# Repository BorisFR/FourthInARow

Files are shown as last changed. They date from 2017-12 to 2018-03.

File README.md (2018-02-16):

# Fourth-In-A-Row

Le jeu des [R2-Builders](https://r2builders.fr) : Le jeu Puissance 4 avec la Force du Jedi !

- Idée originale : [@SuTaiBot](https://twitter.com/RUGeek2)

## ___I. Objectif___

L'objectif est de créer un jeu avec la thématique de Star Wars, par le travail des membres des R2-Builders.  
Le jeu choisi : un dérivé de Puissance 4. Le wikipedia du jeu en français : [Puissance 4](https://fr.wikipedia.org/wiki/Puissance_4). Et le wikipedia en anglais : [Connect 4 ou Four-in-a-row](https://en.wikipedia.org/wiki/Connect_Four). Le jeu sera décliné en deux versions.



### 1. Version dite "classique"

La version classique sera réalisée avec des jetons que l'on dépose dans les colonnes pour jouer, dans le pure style connu de tous, mais au look de Star Wars !

### 2. Version électronique

La version électronique viendra en complément de la version "classique" en supprimant ces jetons et en représentant les jetons par des LEDs et l'on choisira la colonne par des boutons.

### 3. Règles du jeu

Pendant un match, chaque joueur, à tour de rôle, dépose un jeton dans une des sept colonnes. Le jeton tombe au plus bas de la colonne. Une colonne peut contenir 6 jetons au maximum. Un match est gagné quand un des joueurs a aligné 4 jetons à l'horizontale, à la verticale ou en diagonale. S'il n'y a plus de place pour jouer un jeton et qu'il n'y a pas de gagnant, la partie est déclarée match nul.

## ___II. Version classique___

### 1. Le plateau de jeu

Voici un rendu de ce que ça pourrait donner :  
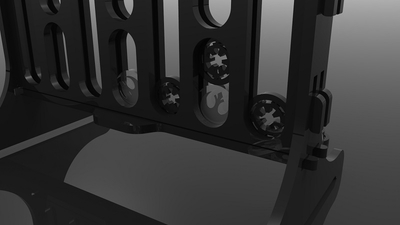
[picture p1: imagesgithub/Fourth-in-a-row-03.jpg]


#### a. Le plateau

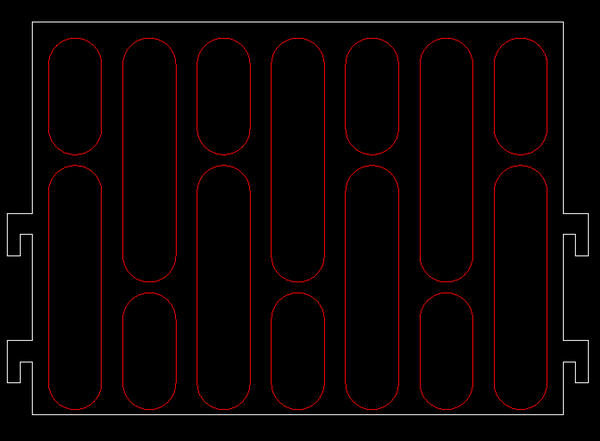
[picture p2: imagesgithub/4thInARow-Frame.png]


#### b. Les supports

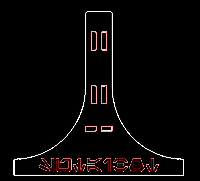
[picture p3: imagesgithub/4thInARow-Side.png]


### 2. Les jetons

plateau

## ___III. Version électronique___

### **1. Fonctionnement**

Le jeu a plusieurs états. Les inter-actions avec les joueurs seront variables en fonction de cet état. Voici le détail pour chaque état.

#### a. Attente

Dans cet phase, il n'y a pas de jeu en cours. Le programme est juste en attente d'une action des joueurs. Il passe alors à l'état suivant ***b***.

#### b. Choix du nombre de joueurs

Ici, il faut déterminer combien de joueurs participe au jeu. Ce nombre peut être de 1 ou 2. Si 2 joueurs est choisit, il s'agit d'un match opposant deux joueurs. Si il n'y a qu'un seul joueur, il jouera alors contre une  "Intelligence Artificielle" (IA). Afin de tester cette IA, il est possible de choisir zéro joueur : le programme joue alors contre lui-même.

#### c. Choix du joueur qui commence

Il faut maintenant décider qui commence parmi les deux opposants. Une fois ce choix effectué, le programme passe alors à l'état ***d***.

#### d. Placer un jeton

Le joueur en cours doit sélectionner une colonne pour déposer son jeton. Le programme passe alors à l'état ***e***.

#### e. Analyser le jeton

Si la colonne est pleine, retour à l'état ***d***.
Si quelqu'un a gagné, à l'état correspondant ***f*** ou ***g***.
S'il n'est plus possible de jouer, aller à l'état ***h***.
C'est au joueur suivant de jouer, aller à l'état ***d***.

#### f. Le joueur 1 a gagné

On affiche l'information et on passe à l'état ***i***.

#### g. Le joueur 2 a gagné

On affiche l'information et on passe à l'état ***i***.

#### h. C'est un match nul

On affiche l'information et on passe à l'état ***i***.

#### i. Animation de fin de jeu

On retourne à l'état ***a***.

### **2. Matériel**
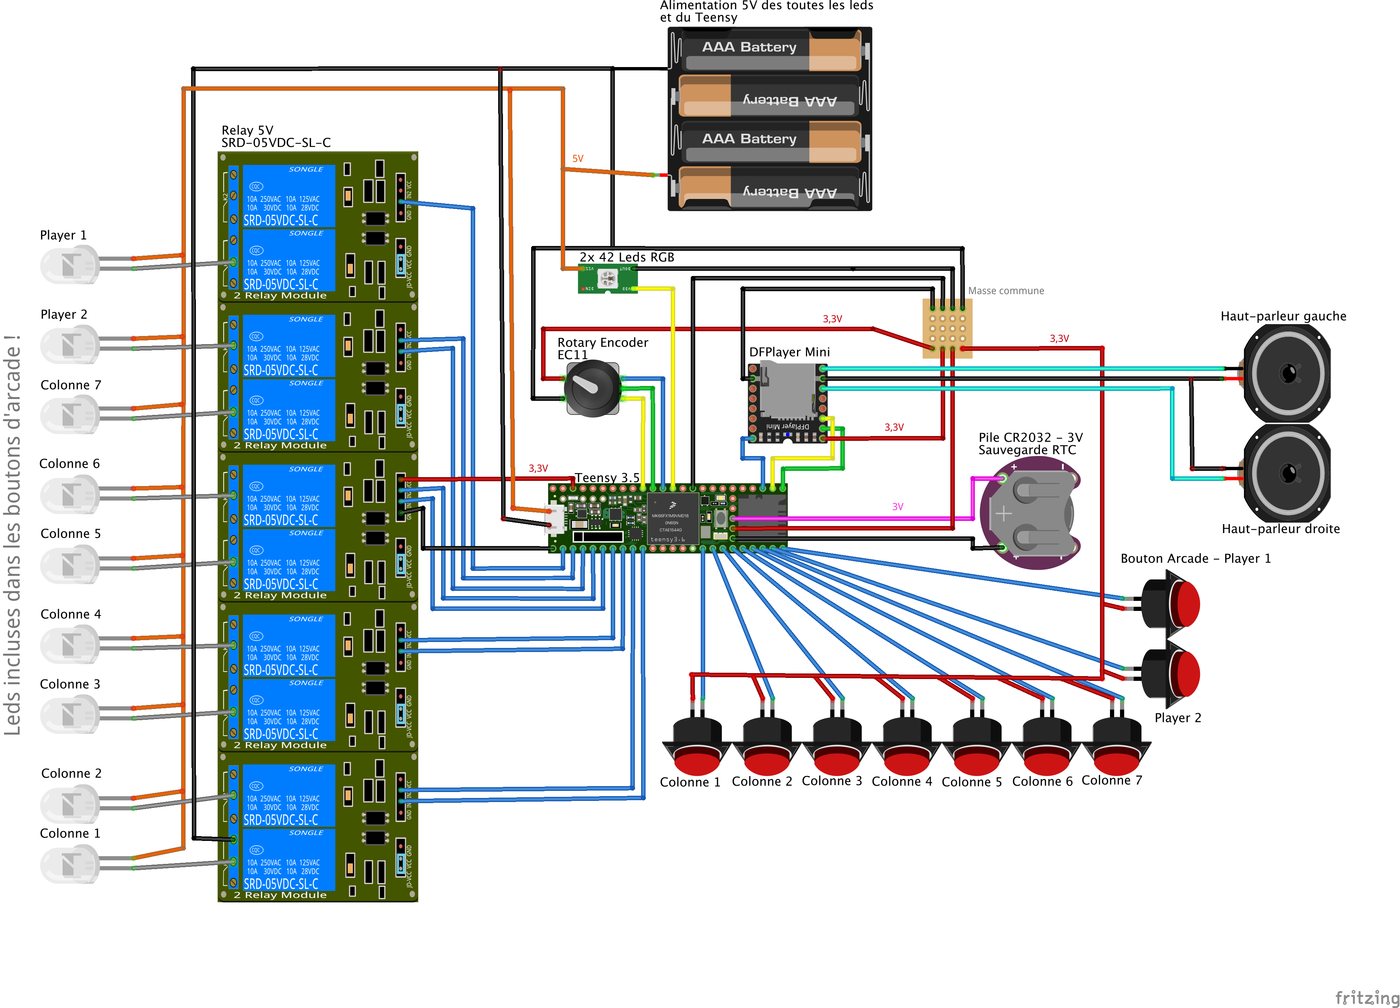
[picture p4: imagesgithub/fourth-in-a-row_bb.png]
Schéma

#### 1. Composant principal

Le cerveau de cette version électronique. On pourra utiliser divers matériels, voici ce que les membres ont utilisés / testés. Le programme fonctionne sur :

- Arduino Mega
- Adafruit Huzzah 32 (ESP32)
- Teensy 3.5

Il fonctionne certainement sur d'autres composants, mais ça n'a pas été testé.

#### 2. Composants additionnels

L'idée est d'avoir un panel d'options pour que vous puissiez réaliser votre propre jeu. Voici l'ensemble des composants qui sont activables dans le programme.

C'est dans le fichier ***"MyConfig.hpp"*** que vous indiquez votre configuration.

##### a. INPUT : Boutons pour jouer

Besoin :

- choisir le nombres de joueurs
- choisir qui commence
- choisir la colonne pour déposer le jeton

##### b. INPUT : Boutons pour audio

Gérer le son : augmenter le volume, baisser le volume, mute.

##### c. OUTPUT - Audio

Avoir la possibilité de jouer du son à divers moments pendant le jeu.

##### d. OUTPUT - LED

L'idée est d'avoir une LED par case, schématisant une case vide ou un jeton de joueur. Le tout représente un jeu complet.

Possibilités :

- 42 LEDs RGB

##### e. OUTPUT - Écran

Avoir un écran graphique sur lequel afficher des animations amusantes pendant le jeu. Pour le moment, cette option ne sera pas développée.

### 3. **Le programme**

Vous pouvez configurer votre installation dans le fichier "MyConfig.hpp". Vous pouvez alors compiler et télécharger votre programme sur votre arduino.

Le programme est développé en C++ "arduino".

#### "FourthInARow.ino"

Le point d'entrée est le fichier "FourthInARow.ino". Il s'agit du chef d'orchestre du jeu, celui qui va gérer les différents états du jeu et orchestrer l'ensemble des composants en fonction de cet état.

#### "Game.hpp"

Les fichiers Game.h et Game.cpp contiennent toute la logique d'exécution du jeu Puissance 4 en lui-même.

#### "GameInput.hpp"

Les fichiers "GameInput.hpp" et "GameInput.cpp" contiennent toute la logique pour que les joueurs puissent agir sur le jeu. A ce titre, c'est ici que l'on définit toutes les entrées possibles comme la gestion des boutons.
C'est fichiers contiennent une implémentation à vide de ces fonctions ! L'implémentation réelle est effectuée dans d'autres fichiers. Il suffit d'indiquer dans le fichier "MyConfig.hpp" l'implémentation réelle que vous voulez utiliser.

Voici les implémentations disponibles :

- GI_serial.hpp/cpp : interface Serial (utilisable uniquement en mode debug).
- GI_9buttons.hpp/.cpp : 7 boutons pour le choix de la colonne et 2 boutons pour le choix du nombre de joueurs.

#### "GameInputAudio.hpp"

Les fichiers "GameInputAudio.h" et "GameInputAudio.cpp" contiennent toute la logique pour agir sur l'audio : gérer le volume, couper le son, ...

Voici les implémentations disponibles concernant le son :

- GIA_ec11.hpp/cpp : encodeur rotatif EC11, pour la gestion du son (volume +/- et mute).

#### "GameOutputAudio.hpp"

Les fichiers "GameOutputAudio.h" et "GameOutputAudio.cpp" contiennent toute la logique pour que le jeu puissent faire du bruit.

Voici les implémentations disponibles concernant le son :

- GOA_DFPlayerMini.hpp/.cpp : mini carte son mp3/wav sur micro SD.

#### "GameOutput.hpp"

Les fichiers "GameOutput.h" et "GameOutput.cpp" contiennent toute la logique pour que le jeu puissent communiquer avec les joueurs. C'est donc ici que l'on gérera l'affichage du plateau de jeu (les LEDs), l'audio et l'affichage d'animations.
Ces fichiers contiennent une implémentation à vide de ces fonctions ! L'implémentation réelle est effectuée dans d'autres fichiers (par héritage de class). Mais pour vous, il suffit d'indiquer dans le fichier "MyConfig.hpp" l'implémentation réelle que vous voulez utiliser.

Voici les implémentations disponibles concernant l'affichage du plateau :

- GO_serial.hpp/.cpp : rendu dans l'interface Série du PC/Mac/Linux
- GO_ws2801.hpp/.cpp : affichage via ruban led type ws2801. utilise la bibliothèque Adafruit_WS2801.
- pour debug lors du dév : GO_FeatherOled.hpp/.cpp : un rendu basique du plateau de jeu sur écran [Featherwing OLED 128x32](https://www.adafruit.com/product/2900). Utilise les bibliothèques Adafruit_SSD1306 et Adafruit_GFX.

#### Autres fichiers

Global.hpp, CaseLocation.hpp, Column.hpp/.cpp, Tile.hpp/.cpp : utile pour le fonctionnement du moteur de jeu.

OneSwitch.hpp/.cpp : bibliothèque que vous pouvez utilisez pour implémenter un bouton avec gestion du debounce.

### 4. **Environnement de développement**

Ce projet est réalisé avec [Visual Studio Code](https://code.visualstudio.com) avec l'extension [PlatformIO](http://platformio.org).  
Cependant, la structure du projet permet d'ouvrir ce projet avec l'environnement [Arduino IDE](https://www.arduino.cc/en/Main/Software) standard.  
Ce projet fonctionne également avec [Atom](https://atom.io) + [PlatformIO](http://platformio.org).  

### Sur Mac

Il faut un git avec une version au moins 2.0.0  
git --version  
git version 2.13.5 (Apple Git-94)  
  
git credential-osxkeychain  
usage: git credential-osxkeychain <get|store|erase>  
  
git config --global credential.helper osxkeychain  

[GitHub Desktop](https://desktop.github.com)

**********************************************************

## Liste des composants par Boris

C'est un premier jet, il serait étonnant que j'ai tout bon du premier coup ;) J'indique "*OK!*" quand le composant est en place.

**Alimentation :** 5V 10A - [https://fr.aliexpress.com/item/AC-DC-Power-Supply-5V-5A-6A-8A-10A-Adapter-Charger-Transformer-25W-60W-40W-50W/32756921792.html](https://fr.aliexpress.com/item/AC-DC-Power-Supply-5V-5A-6A-8A-10A-Adapter-Charger-Transformer-25W-60W-40W-50W/32756921792.html)  

**Connecteur d'alimentation :** Jack 5,5mm / 2,1mm - réf 48138 - [https://www.gotronic.fr/art-embase-alim-sa21a-14961.htm](https://www.gotronic.fr/art-embase-alim-sa21a-14961.htm) *<= OK!*  

**Electronique :** Huzzah32 - [https://www.adafruit.com/product/3405](https://www.adafruit.com/product/3405) *<= OK!*  

**Haut-parleur :** 2x 3W 8 Ohms - réf 05527 - [https://www.gotronic.fr/art-haut-parleur-hp8r3w-25596.htm](https://www.gotronic.fr/art-haut-parleur-hp8r3w-25596.htm) *<= OK!*  

**Ampli audio :** 2,8 W - réf 32946 - [https://www.gotronic.fr/art-module-ampli-audio-2-8w-ada1552-21902.htm](https://www.gotronic.fr/art-module-ampli-audio-2-8w-ada1552-21902.htm) *<= OK!*  

**Carte son:** DFPlayer Mini - [https://www.gotronic.fr/art-module-mp3-dfr0299-22404.htm](https://www.gotronic.fr/art-module-mp3-dfr0299-22404.htm) *<= OK!*  

**Bouton de commande audio :** encodeur rotatif - ref 35409 - [https://www.gotronic.fr/art-module-encodeur-rotatif-sen0235-26820.htm](https://www.gotronic.fr/art-module-encodeur-rotatif-sen0235-26820.htm) *<= OK!*  

**Boutons pour jouer :** boutons d'arcade lumineux 30mm - [https://fr.aliexpress.com/item/10pcs-lot-30mm-Push-Button-Arcade-Button-5V-LED-Illuminated-Push-Button-LED-1P-2P-Start/32807197485.html](https://fr.aliexpress.com/item/10pcs-lot-30mm-Push-Button-Arcade-Button-5V-LED-Illuminated-Push-Button-LED-1P-2P-Start/32807197485.html)  

**Affichage du plateau par LEDs :** 2x Ruban 50 LEDs RGB - [https://fr.aliexpress.com/item/50pcs-WS2813-IC-pixel-LED-Module-lighting-F9-for-sign-DC5V-IP68-Waterproof-super-bright-WS2818/32803390301.html](https://fr.aliexpress.com/item/50pcs-WS2813-IC-pixel-LED-Module-lighting-F9-for-sign-DC5V-IP68-Waterproof-super-bright-WS2818/32803390301.html)  

**********************************************************

## Des liens

Aide pour la [mise en forme de ce readme](https://openclassrooms.com/courses/redigez-en-markdown).

Viewer DXF sur Mac : https://github.com/LibreCAD/LibreCAD/releases

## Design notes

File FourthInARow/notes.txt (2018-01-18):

quelques réflexions sur le jeu

le joueur doit savoir de quelle couleur il est !

Jeu à 1 ou 2

Si jeu à 1, joue contre :
niveau 7 : le plus fort => R2-D2 bien sûr ! (contre lui, on ne peut que faire match nul au mieux)
niveau 6 : plutôt bon => BB-8
niveau 5 : pervers => BB-9E
niveau 4 : avec la force => Yoda
niveau 3 :
niveau 2 : 
niveau 1 : le plus faible => Jar Jar Binks (totalement aléatoire, voir joue pour aider l'adversaire)

prévoir une aide pour le joueur => lui montrer un bon coup à jouer ou une case à jouer pour contrer

en mode "économiseur d'écran", ça peut être IA contre IA.

Si jeu à 2, chacun choisit son joueur :
Joueur 1 : Luc
Joueur 2 : Poe
Joueur 3 : Leia
Joueur 4 : 
Joueur 5 : 
Joueur 6 : 
Joueur 7 : 

hum... plutôt choisir un camp genre rebel, empire, chasseur de prime, etc... avec une banque sonore correspondante... à construire...

** DEV

Comment implémenter un composant hardware
Créer la class C++ correspondante, qui hérite des call standard mise à disposition :
Pour gérer des entrées utilisateurs : GameInput
Pour gérer une sorties visuelles du jeu : GameOutput
Pour gérer du son : GameOutputAudio
Ces class contiennent le fonctionnement "à vide", sans composant hardware.

Pour intégrer votre hardware, il faut surcharger les fonctions qui vous sont utiles pour votre hardware.

Il y a la fonction "setup()" qui sert à initialiser votre composant. C'est appeler une seule fois.
Puis il y a la fonction classique "loop()" qui est exécutée en permanence. Si nécessaire, à la place, vous pouvez utiliser "startLoop()" qui est appelé au début de la boucle loop() et "endLoop()" qui est appelé à la fin de la boucle "loop()".

Détail de GameInput
Cela sert à prendre en compte les actions de l'utilisateur.
L'action qui est attendue est de renseigner la variable "input" de type inputAction (voirGlobal.h).

Détail pour GameOutput
Cette class sert à montrer des choses aux joueurs.
Si avec votre hardware vous devez dessinez le plateau de jeu, il faut implémenter la fonction "drawGrid()".
Pour effacer les cases (vider les pions), il faut implémenter "clearTiles()".
Pour dessiner un pion, il faut implémenter "setTiles(CaseLocation location, Player token)" : location contient la ligne et la colonne, player correspond à joueur.
Ou alors, vous pouvez simplement implémenter la fonction "drawBoard(Column board[BOARD_COLUMNS]" et vous redessinez l'ensemble du plateau de jeu à chaque fois. 1 colonne comprenant les 6 cases correspondantes.

Détail pour GameOutputAudio
Cette class à pour but de gérer la carte son et de jouer du bruitage/son.
Pour la gestion, vous avez les fonctions :
volumeUp()
volumeDown()
setVolume(uint8_t value)
getVolume()
muteOn()
muteOff()
+ de nombreuses fonctions pour jouer du son à divers moment du jeu. (voir le fichier GameOutputAudio.hpp pour le détail)

HUZZAH32
seulement en input
X A2/I34, X A3/I39, X A4/36 (A13/I35 mais n'est pas exposé)
seulement en output
A11/I12
input et output
A0/I26, A1/I25, X A5/I4, X I21
X A12/I13 (+red led), X A10/I27, X A9/I33, X A8/I15, X A7/I32, X A6/I14
X SCK/5, X MOSI/18, MISO/19, X SCL/22, X SDA/23

WS2801 de LightBerry : +5V / GND / DATA / CLOCK
encoche au dessus en haut
 clock /  data /  gnd   /  5V
orange / jaune / marron / rouge

ws2813
rouge : 5V
blanc : GND
vert : signal
bleu : doublon du vert, pas obligatoire

Lib FastLED, mas celle-ci : (pour ESP32 et WS2813)
https://github.com/samguyer/FastLED

Dossier sons carte SD pour DFPlayer Mini
folder					#files
01 : power on			2
02 : push button bad	4
03 : push button good	7
04 : start game			4
05 : IA thinking		10
06 : player could loose 9
07 : player could win	12
08 : player will loose	9
09 : game loose			7
10 : game win			5

sur Mac, ne pas oublier de nettoyer la carte SD avec : dot_clean /Volumes/<SDVolumeName>

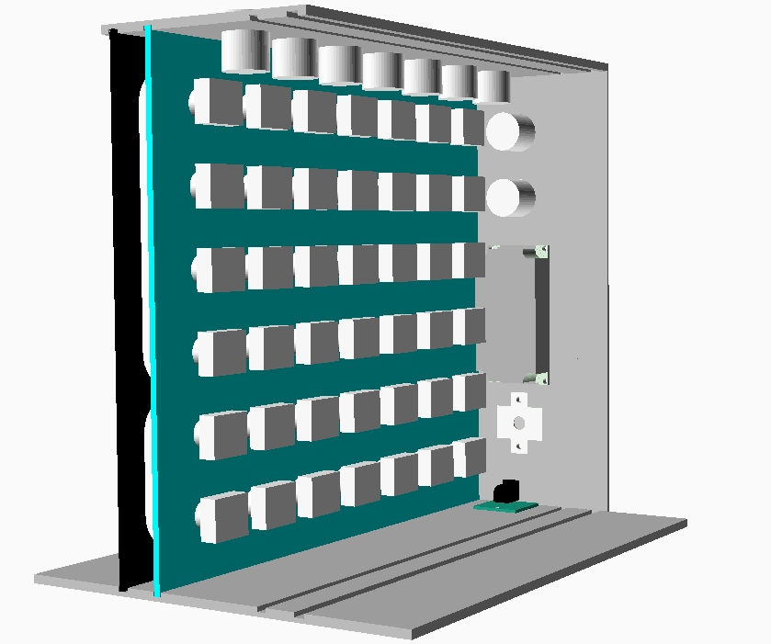
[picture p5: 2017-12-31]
modelisation/openscad Boris/interieur.png

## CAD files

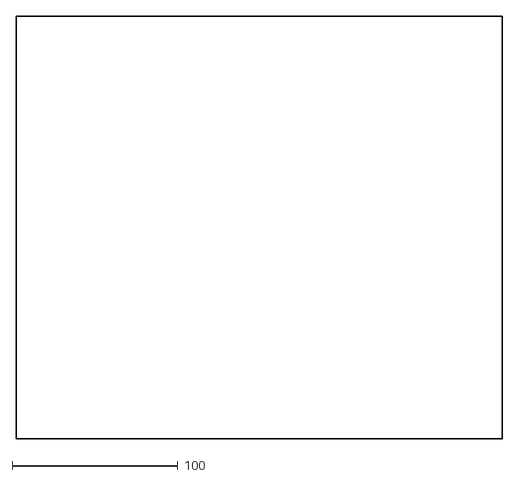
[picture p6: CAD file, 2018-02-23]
modelisation/openscad Boris/DFX3/plexi blanc mur.dxf
293.1 x 254.8

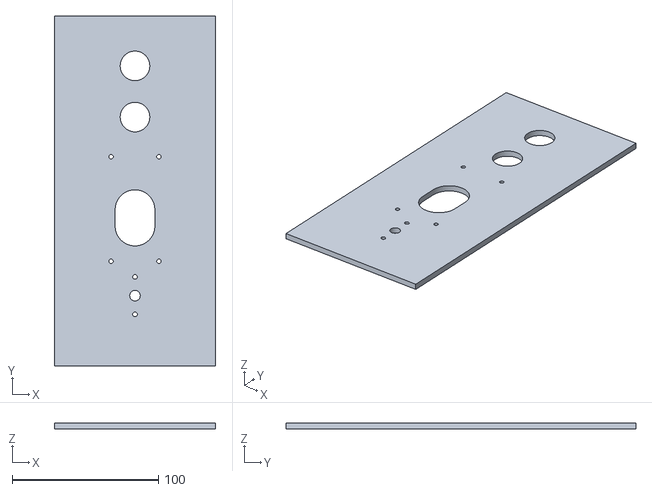
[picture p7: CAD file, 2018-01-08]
modelisation/openscad Boris/stl/cote_droit.stl
110.0 x 239.0 x 4.00

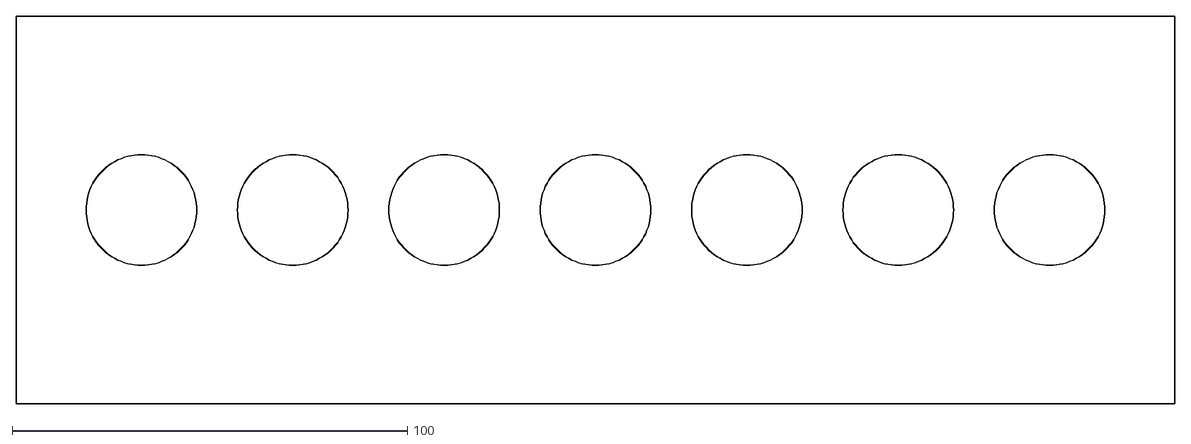
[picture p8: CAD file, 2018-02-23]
modelisation/openscad Boris/DFX3/dessus.dxf
293.1 x 98.0

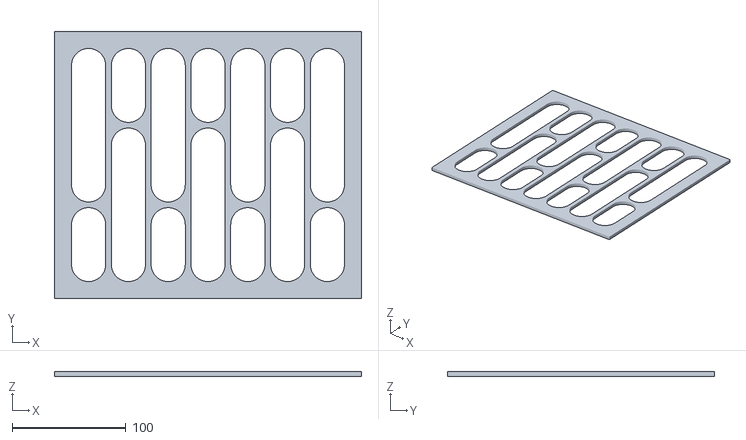
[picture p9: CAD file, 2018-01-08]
modelisation/openscad Boris/stl/mur.stl
270.0 x 235.0 x 4.00

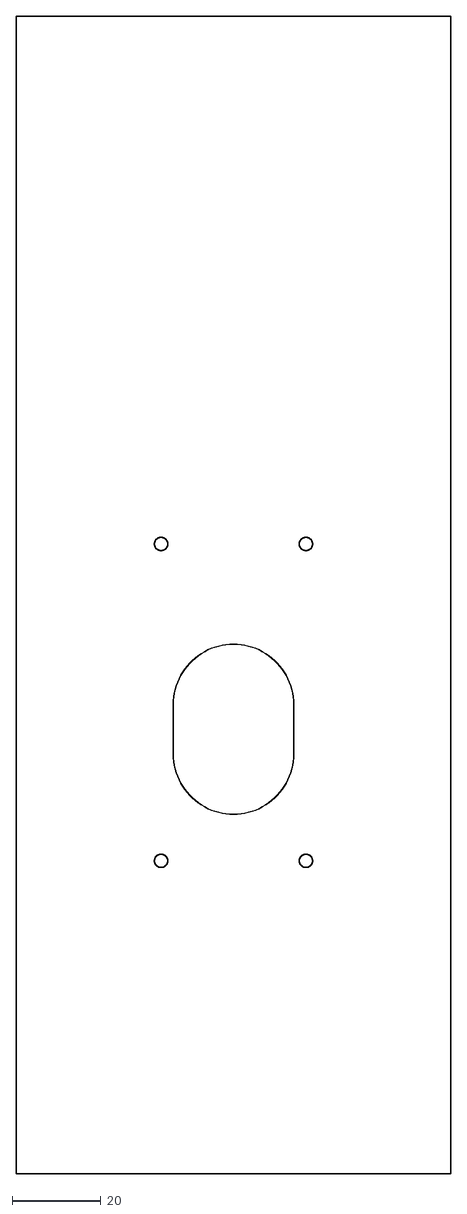
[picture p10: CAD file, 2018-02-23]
modelisation/openscad Boris/DFX3/cote_gauche.dxf
98.0 x 260.8

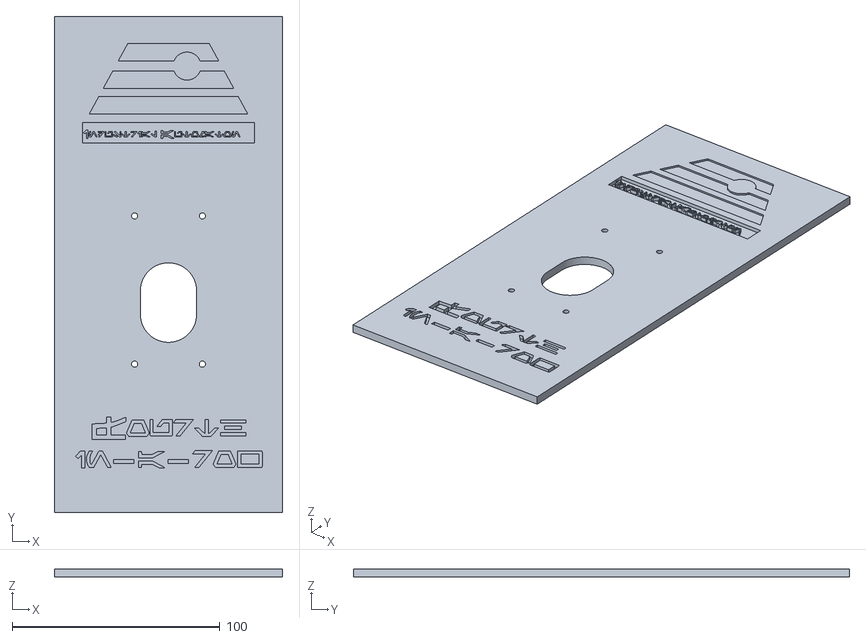
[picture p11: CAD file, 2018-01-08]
modelisation/openscad Boris/stl/cote_gauche.stl
110.0 x 239.0 x 4.00

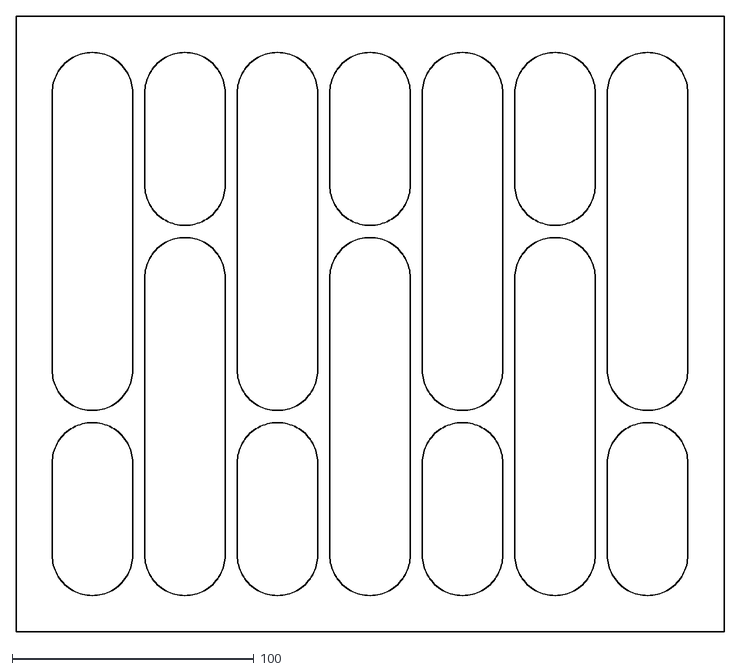
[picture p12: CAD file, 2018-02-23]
modelisation/openscad Boris/DFX3/mur.dxf
293.1 x 254.8

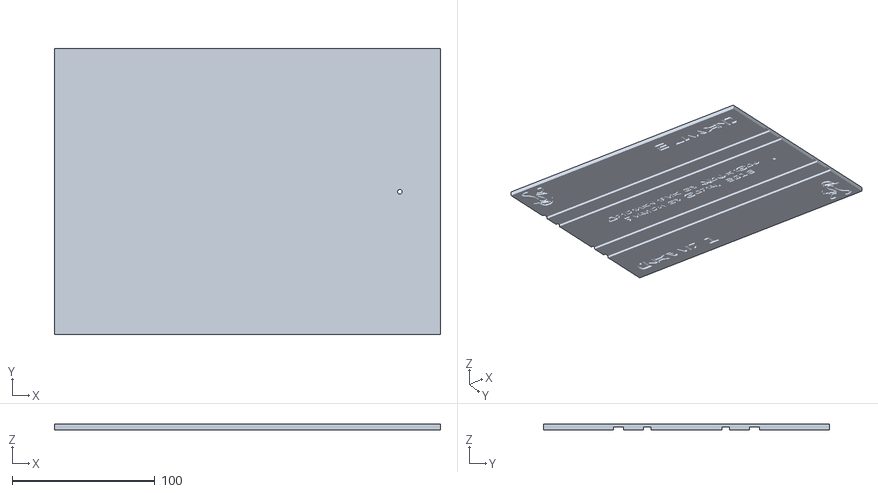
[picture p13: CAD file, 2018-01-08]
modelisation/openscad Boris/stl/dessous.stl
270.0 x 200.0 x 4.00

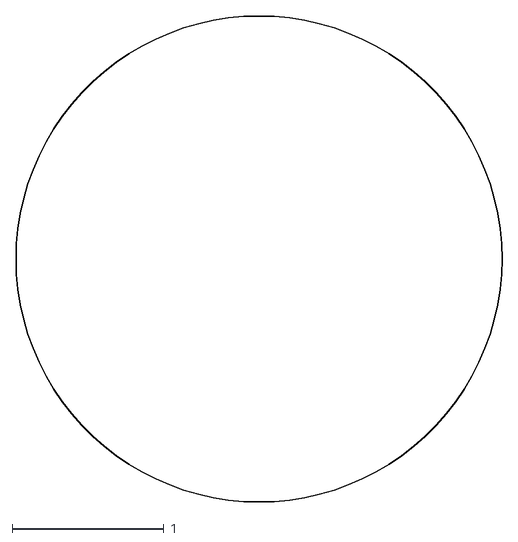
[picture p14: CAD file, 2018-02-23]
modelisation/openscad Boris/DFX3/dessous.dxf
3.20 x 3.20

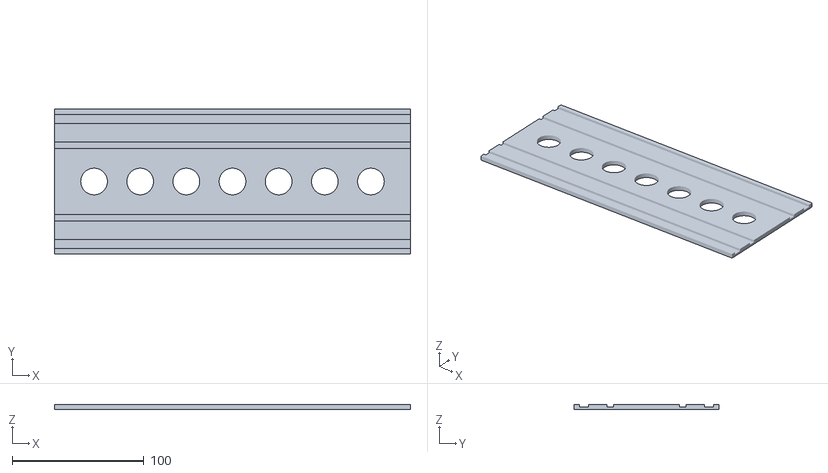
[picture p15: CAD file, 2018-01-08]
modelisation/openscad Boris/stl/dessus.stl
270.0 x 110.0 x 4.00

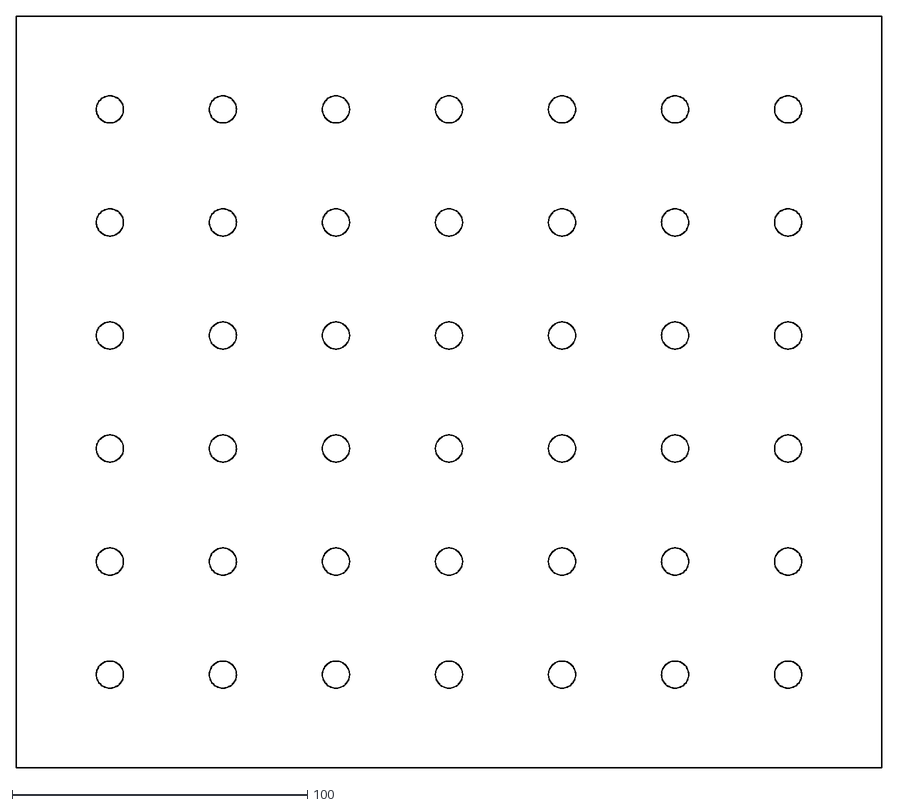
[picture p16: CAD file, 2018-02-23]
modelisation/openscad Boris/DFX3/grille_led.dxf
293.1 x 254.8

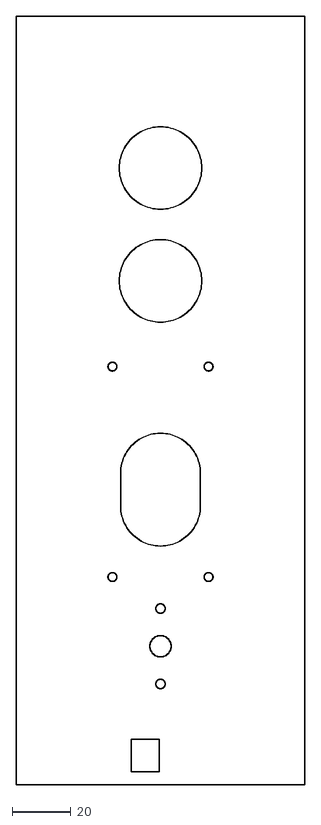
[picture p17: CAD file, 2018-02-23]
modelisation/openscad Boris/DFX3/cote_droit.dxf
98.0 x 260.8

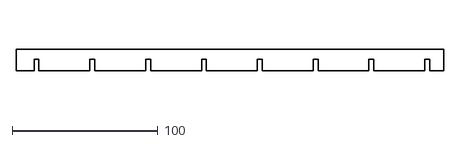
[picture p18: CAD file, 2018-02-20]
modelisation/openscad Boris/DFX3/spacerH.dxf
293.1 x 15.0

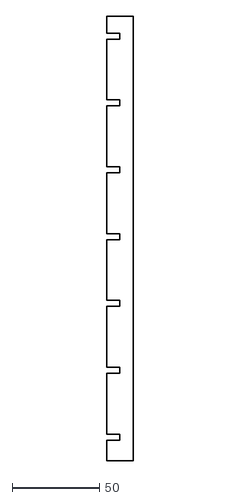
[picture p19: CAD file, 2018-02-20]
modelisation/openscad Boris/DFX3/spacerV.dxf
15.0 x 254.8

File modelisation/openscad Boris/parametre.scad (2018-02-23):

/* pour le rendu openscad */

// pour la finesse de rendu
// plus c'est élevé, mieux c'est... mais ça prend plus de temps et de ressource
resolution = 100;

// pour export DXF
show_mode_projection = 1;

// pour enlever de la matière des objets dans openscad et être certain qu'il ne reste pas un bout de face
difference_objet_marge = 20;

// pour afficher (1) ou pas (0) les accessoires installés
show_accessoires = 0;

show_incrustations = 1;

show_logo_r2builders = 0;



/* pour le design du jeu  */

// tout est en millimetre !!!!

// configuration globale
////////////////////////

// quand on perce et que l'on va insérer quelque chose dedans...
// il faut un peu de vide en plus ;)
padding_percage = 0.2;

// espace supplémentaire pour la largeur de rainure
padding_rainure = 0; // 1

// profondeur standard pour une rainure
profondeur_rainure = 0; // 2 // moins que epaisseur_tole_grille_led et que epaisseur_tole_grille_led ! Il faut qu'il reste de la matière !

// définition de base du jeu
nombre_colonnes = 7;
nombre_lignes = 6;


// les boutons de sélection de colonne et du nombre de joueurs
//////////////////////////////////////////////////////////////
diametre_bouton_arcade = 33.3;
rayon_bouton_arcade = diametre_bouton_arcade / 2;
diametre_trou_bouton_arcade = 27.8;
rayon_trou_bouton_arcade = diametre_trou_bouton_arcade / 2;
hauteur_bague_bouton_arcade = 4.7;
hauteur_bouton_arcade = 4.85;
diametre_push_bouton_arcade = diametre_bouton_arcade - 4;
profondeur_interne_bouton_arcade = 33.5;


// bouton EC11
//////////////
diametre_bouton_ec11 = 14.4;
hauteur_bouton_ec11 = 13.1;
epaisseur_trait_ec11 = 1;
trou_axe_ec11 = 7;
espace_platine_bouton = 10.7;
hauteur_platine_ec11 = 33.4;
largeur_platine_ec11 = 27.5;
epaisseur_platine_ec11 = 1.3;
trou_fixation_ec11 = 3;
trou_marge_ec11 = 2.40;


// haut-parleur HP8R
////////////////////
HP8R_epaisseur_totale = 16.25;
HP8R_largeur = 36.24;
HP8R_hauteur = 75;
HP8R_epaisseur_tole = 1.63;
HP8R_hauteur_caisson = 71;
//HP8R_epaisseur_caisson = 16.25 - HP8R_epaisseur_tole;
HP8R_decalage_hauteur_trou = 12.3;
HP8R_largeur_trou = 27.1;
HP8R_hauteur_trou = 38.3;
HP8R_epaisseur_trou = HP8R_epaisseur_totale - 2;
HP8R_diametre_creuse_coins = 10;
HP8R_diametre_creuse_fixation = 3;
HP8R_marge_creuse_fixation = 1.6 + padding_percage;


// Embase alimentation
//////////////////////
embase_decallage = 3.3;
embase_externe_largeur = 8.95;
embase_externe_hauteur = 10.7;
embase_externe_profondeur = 3.5;
embase_externe_marge_trou = 3.3;
embase_externe_diametre_trou = 6.4;
embase_externe_diametre_pin = 1.6;
embase_interne_profondeur = 10.6;
embase_platine_profondeur = 25.5;
embase_platine_decallage = 5.6;
embase_platine_largeur = 25.9;
embase_platine_epaisseur = 1.6;
embase_marge_fixation = 1.5;
embase_diametre_fixation = 3;


// led type1 : LED étanche avec électronique carré
////////////
profondeur_chapeau_led = 7.5;
diametre_trou_led = 9;
diametre_interne_led = 9;
profondeur_interne_led = 0;
boitier_largeur_led = 17.2;
boitier_hauteur_led = 11.2;
boitier_epaisseur_led = 5;


// pour stocker les cables et l'électronique
////////////////////////////////////////////
espace_vide_milieu = 40; // TODO: à valider !   vérifier qu'il n'y a pas de conflit entre bouton et led en haut !!!


// le mur Star Wars fenetré
///////////////////////////
epaisseur_tole_mur = 3;
taille_fenetre = diametre_bouton_arcade; // valeur à fixer si bouton plus petit, ici je m'adapte à cette taille de bouton
ecart_entre_fenetre = 5; // au jugé ;)
marge_mur = 15; // pour aérer le tour   10 => haut parleur touche led et conflit bouton dans le coin !


// cadrillage autour des LEDs
/////////////////////////////
profondeur_separateur_led = 15; // TODO: à valider !
epaisseur_separateur_led = 3;
decallage_separateur_led = (ecart_entre_fenetre - epaisseur_separateur_led) / 2;


// on peut maintenant calculer la surface du jeu !
largeur_mur = marge_mur + (nombre_colonnes * taille_fenetre) + ((nombre_colonnes - 1) * ecart_entre_fenetre) + marge_mur;
hauteur_mur = marge_mur + (nombre_lignes * taille_fenetre) + ((nombre_lignes - 1) * ecart_entre_fenetre) + marge_mur;
echo(str("** PLAQUE MUR (x2) : ", largeur_mur , " x ", hauteur_mur, " x ", epaisseur_tole_mur));


// la grille de LEDS
////////////////////
epaisseur_tole_grille_led = 3;
largeur_rainure_grille_led = epaisseur_tole_grille_led + padding_rainure;
profondeur_rainure_grille_led = profondeur_rainure; // moins que epaisseur_tole_grille_led !!!
echo(str("** PLAQUE GRILLE LED (x2) : ", largeur_mur , " x ", hauteur_mur, " x ", epaisseur_tole_grille_led));


// le plexi blanc derrière le mur, pour faire les fenêtres
//////////////////////////////////////////////////////////
epaisseur_plexi_blanc = 3;
transparence_plexi = 1;
echo(str("** PLAQUE PLEXI BLANC (x2) : ", largeur_mur , " x ", hauteur_mur, " x ", epaisseur_plexi_blanc));


// calcul de l'épaisseur complète du jeu
epaisseur_jeu = espace_vide_milieu + 2 * epaisseur_tole_mur + 2 * epaisseur_plexi_blanc + 2 * epaisseur_tole_grille_led + 2 * profondeur_separateur_led;


// la plaque du dessus avec les boutons de choix de colonne
///////////////////////////////////////////////////////////
epaisseur_tole_dessus = 3; // ce "chapeau" sera rainurée pour tenir les plaques !
debord_rainure = 5; // qui dépasse de devant et derrière 
profondeur_dessus = epaisseur_jeu + 2 * debord_rainure;
marge_largeur_dessus = (largeur_mur - (nombre_colonnes * diametre_bouton_arcade) - ((nombre_colonnes - 1) * ecart_entre_fenetre)) / 2;
largeur_rainure_mur_plexi = epaisseur_tole_mur + epaisseur_plexi_blanc + padding_rainure;
profondeur_rainure_mur_plexi = profondeur_rainure; // moins que epaisseur_tole_dessus !!!
echo(str("** PLAQUE DESSUS : ", largeur_mur , " x ", profondeur_dessus, " x ", epaisseur_tole_dessus));


// la plaque de dessous
///////////////////////
epaisseur_tole_dessous = 3; // ce socle sera rainurée pour tenir les plaques !
dessous_debord_rainure = 50;
profondeur_dessous = epaisseur_jeu + 2 * dessous_debord_rainure;
echo(str("** PLAQUE SOCLE : ", largeur_mur , " x ", profondeur_dessous, " x ", epaisseur_tole_dessous));


hauteur_cote = epaisseur_tole_dessous + hauteur_mur + epaisseur_tole_dessus - 2 * profondeur_rainure_grille_led;
largeur_cote = profondeur_dessus;


// côté gauche
//////////////
epaisseur_tole_gauche = 3;
echo(str("** PLAQUE COTE GAUCHE : ", largeur_cote , " x ", hauteur_cote, " x ", epaisseur_tole_gauche));


// côté droit
/////////////
epaisseur_tole_droit = 3;
position_ec11 = epaisseur_tole_dessous + embase_platine_epaisseur + embase_externe_hauteur + 15 + hauteur_platine_ec11 / 2; // 15 = taille d'une pinouille arduino connectée sur l'embase
echo(str("** PLAQUE COTE DROIT : ", largeur_cote , " x ", hauteur_cote, " x ", epaisseur_tole_droit));

position_haut_parleur_HP8R = position_ec11 + hauteur_platine_ec11 / 2 + 5;

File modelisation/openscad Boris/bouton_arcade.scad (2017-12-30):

include <parametre.scad>

bouton_arcade();

module bouton_arcade() {
	union() {
		cylinder(hauteur_bague_bouton_arcade, d=diametre_bouton_arcade, $fn=resolution);
		translate([0, 0, -hauteur_bouton_arcade])
			cylinder(hauteur_bouton_arcade, d=diametre_push_bouton_arcade, $fn=resolution);
		translate([0, 0, hauteur_bague_bouton_arcade])
			cylinder(profondeur_interne_bouton_arcade, d=diametre_trou_bouton_arcade, $fn=resolution);
	}
}

module trou_bouton_arcade(epaisseur) {
	translate([0, 0, -difference_objet_marge / 2])
		cylinder(epaisseur + difference_objet_marge, d=diametre_trou_bouton_arcade + padding_percage, $fn=resolution);
}

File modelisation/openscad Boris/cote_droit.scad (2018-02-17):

include <parametre.scad>
use <bouton_arcade.scad>
use <haut_parleur_HP8R.scad>
use <ec11.scad>
use <embase.scad>

use <logo_man.scad>


// pour exporter en .dxf
if(show_mode_projection == 1)
	projection(cut = false) cote_droit();

if(show_mode_projection == 0)
	translate([-largeur_cote / 2, 0, 0]) cote_droit();

// plaque mur déco
module cote_droit() {
    color("Silver") {
        difference() {
			// une belle dalle
            cube(size=[largeur_cote, hauteur_cote, epaisseur_tole_droit]);
			
			// les trous player 1 et player 2
			pose_trous_bouton();
			
			// trou haut-parleur 
			translate([(largeur_cote - HP8R_largeur) / 2, position_haut_parleur_HP8R, 0])
				haut_parleur_HP8R_trous();
			
			// trou axe bouton EC11
			translate([largeur_cote / 2, position_ec11, epaisseur_tole_droit])
				trous_ec11(epaisseur_tole_droit);
			
			// embase
			translate([largeur_cote / 2 - embase_platine_largeur / 2, epaisseur_tole_dessous, 0])
				embase_trou(); 
			
			// Dessins sur la plaque
			if(show_incrustations == 1)
			translate([0, 0, 0]) {
				
				// player 1
				translate([largeur_cote - (largeur_cote / 2 - rayon_bouton_arcade) / 2, 
					hauteur_cote - rayon_bouton_arcade - epaisseur_tole_dessus - marge_mur, -padding_percage])
						scale([0.05, 0.05, 1])
							logo_man(2);

				// player 2
				translate([largeur_cote - (largeur_cote / 2 - rayon_bouton_arcade) / 2, 
					hauteur_cote- rayon_bouton_arcade - epaisseur_tole_dessus - marge_mur - taille_fenetre - ecart_entre_fenetre, -padding_percage])
						scale([0.05, 0.05, 1])
							logo_man(2);
				translate([ (largeur_cote / 2 - rayon_bouton_arcade) / 2, 
					hauteur_cote- rayon_bouton_arcade - epaisseur_tole_dessus - marge_mur - taille_fenetre - ecart_entre_fenetre, -padding_percage])
						scale([0.05, 0.05, 1])
							logo_man(2);

				// V1.0
				translate([largeur_cote - 3, epaisseur_tole_dessous + embase_decallage, epaisseur_tole_droit - 2 - 0])
					rotate([180, 0, 180])
						linear_extrude(height = 2 + padding_percage)
							text("Version 1.0", halign = "left", size = 3, font = "Aurabesh");
				
			}
			
		}
	}
	
	if(show_accessoires == 1) {
		
		// bouton player 1
		translate([largeur_cote / 2, 
				hauteur_cote - epaisseur_tole_dessus - marge_mur - profondeur_interne_bouton_arcade, 
				-hauteur_bague_bouton_arcade]) 
			color([1, 1, 1]) bouton_arcade();
		
		// bouton player 2
		translate([largeur_cote / 2, 
				hauteur_cote - epaisseur_tole_dessus - marge_mur - profondeur_interne_bouton_arcade - taille_fenetre - ecart_entre_fenetre, 
				-hauteur_bague_bouton_arcade]) 
			color([1, 1, 1]) bouton_arcade();
	
		// le haut-parleur
		translate([(largeur_cote - HP8R_largeur) / 2, position_haut_parleur_HP8R, epaisseur_tole_droit])
			haut_parleur_HP8R();
		
		// le bouton EC11
		translate([largeur_cote / 2, position_ec11, epaisseur_tole_droit])
			mirror([0, 0, 1])
				ec11();

		// embase
		translate([largeur_cote / 2 - embase_platine_largeur / 2, epaisseur_tole_dessous, 0])
			embase(); 
	}

}

module pose_trous_bouton() {
	translate([largeur_cote / 2, 
			hauteur_cote - epaisseur_tole_dessus - marge_mur - profondeur_interne_bouton_arcade, 
			- difference_objet_marge / 2]) 
		trou_bouton_arcade(epaisseur_tole_droit + difference_objet_marge);

	translate([largeur_cote / 2, 
			hauteur_cote - epaisseur_tole_dessus - marge_mur - profondeur_interne_bouton_arcade - taille_fenetre - ecart_entre_fenetre, 
			- difference_objet_marge / 2]) 
		trou_bouton_arcade(epaisseur_tole_droit + difference_objet_marge);
}

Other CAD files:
modelisation/openscad Boris/dxf/grille_led.dxf
modelisation/openscad Boris/cote_gauche.scad
modelisation/openscad Boris/dessous.scad
modelisation/openscad Boris/dessus.scad
modelisation/openscad Boris/dxf/cote_droit.dxf
modelisation/openscad Boris/dxf/cote_gauche.dxf
modelisation/openscad Boris/dxf/dessous.dxf
modelisation/openscad Boris/dxf/dessus.dxf
modelisation/openscad Boris/dxf/mur.dxf
modelisation/openscad Boris/ec11.scad
modelisation/openscad Boris/embase.scad
modelisation/openscad Boris/grille_led.scad
modelisation/openscad Boris/haut_parleur_HP8R.scad
modelisation/openscad Boris/jeu complet.scad
modelisation/openscad Boris/led_rgb_type1.scad
modelisation/openscad Boris/logo_club_forme.scad
modelisation/openscad Boris/logo_ia.scad
modelisation/openscad Boris/logo_man.scad
modelisation/openscad Boris/mur.scad
modelisation/openscad Boris/plexi blanc mur.scad
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

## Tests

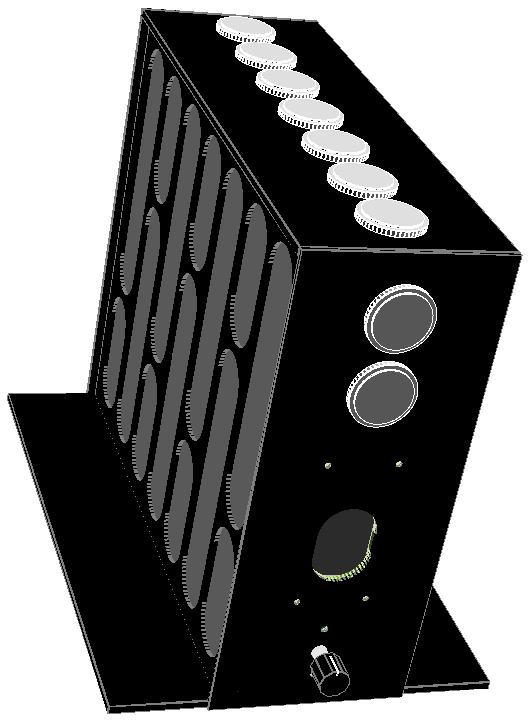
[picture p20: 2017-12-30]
modelisation/openscad Boris/test.png

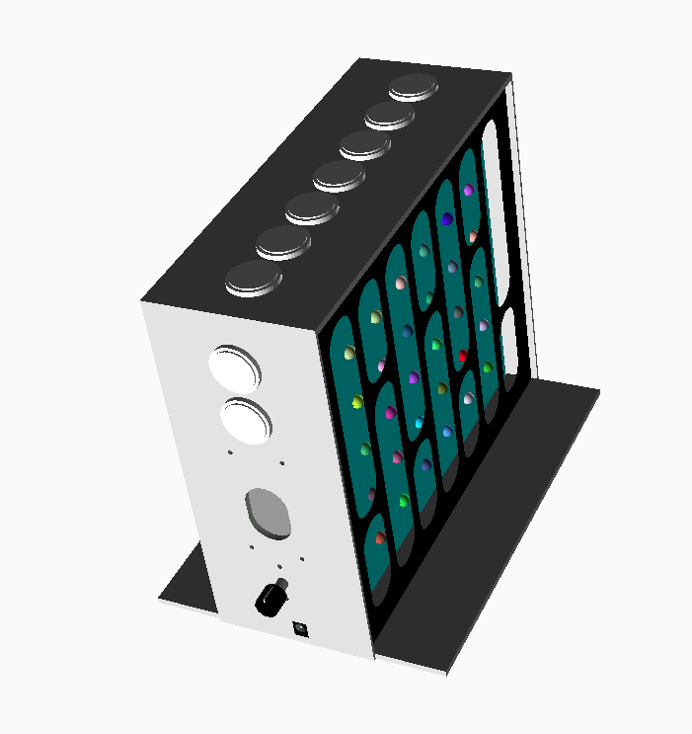
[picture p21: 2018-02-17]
modelisation/openscad Boris/test2.png

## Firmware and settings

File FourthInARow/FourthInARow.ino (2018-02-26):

#include "Global.hpp"

uint8_t playLine;
uint8_t playColumn;
bool winner;
bool player1IsIA;
bool player2IsIA;


////////////////////////////////////////////////////////////////////////////////
// HELPER
////////////////////////////////////////////////////////////////////////////////

#if DEBUG

void debug(String text)
{
	Serial.print(text);
	//Serial.print(text);
}

// only call one time, starting the program
void doInitHelper()
{
	Serial.begin(115200);
	debug(F("Init Debug: OK\n"));
}

#endif


////////////////////////////////////////////////////////////////////////////////
// GAME
////////////////////////////////////////////////////////////////////////////////

// INPUT
// *****

#if GAME_INPUT_DUMMY
	#include "GameInput.hpp"
	GameInput gameInput;
#endif
#if GAME_INPUT_SERIAL
	#include "GI_serial.hpp"
	GIserial gameInput;
#endif
#if GAME_INPUT_9BUTTONS
	#include "GI_9buttons.hpp"
	GI9buttons gameInput;
	#if BUTTONS_LED
		#include "ButtonsLed.hpp"
		ButtonsLed buttonsLed;
	#endif
#endif

// OUTPUT
// ******

#if GAME_OUTPUT_DUMMY
	#include "GameOutput.hpp"
	GameOutput gameOutput;
#endif
#if GAME_OUTPUT_SERIAL
	#include "GO_serial.hpp"
	GOserial gameOutput;
#endif
#if GAME_OUPUT_WS2801
	#include "GO_ws2801.hpp"
	GO_ws2801 gameOutput;
#endif
#if GAME_OUPUT_WS2813
	#include "GO_ws2813.hpp"
	GO_ws2813 gameOutput;
#endif
#if GAME_OUTPUT_FEATHER_OLED
	#include "GO_FeatherOled.hpp"
	GOFeatherOled gameOutput;
#endif

// AUDIO
// *****
#if GAME_INPUT_AUDIO_DUMMY
	#include "GameInputAudio.hpp"
	GameInputAudio gameInputAudio;
#endif
#if GAME_INPUT_AUDIO_EC11
	#include "GIA_ec11.hpp"
	GIAec11 gameInputAudio;
#endif
#if GAME_OUTPUT_AUDIO_DUMMY
	#include "GameOutputAudio.hpp"
	GameOutputAudio gameOutputAudio;
#endif
#if GAME_OUTPUT_AUDIO_DFPLAYER_MINI
	#include "GOA_DFPlayerMini.hpp"
	GOA_DFPlayerMini gameOutputAudio;
#endif

#include "Game.hpp"
Game game;

// only call one time, starting the program
void doInitGame()
{
	game.gameState = waitingTouch;
#if DEBUG
	gameInput.doInit(debug);
	gameOutput.doInit(debug);
	gameInputAudio.doInit(debug);
	gameOutputAudio.doInit(debug);
	game.doInit(debug);
	#if BUTTONS_LED
		buttonsLed.doInit(debug);
	#endif
#else
	gameInput.doInit();
	gameOutput.doInit();
	gameInputAudio.doInit();
	gameOutputAudio.doInit();
	game.doInit();
	#if BUTTONS_LED
		buttonsLed.doInit();
	#endif
#endif
	gameOutput.setup();
	gameOutput.drawGrid();
	gameInputAudio.setup();
	gameOutputAudio.setup();
	startAnimWaitingPlayers();
}

// set gamestate at who is playing now
void gameTurn()
{
	if(!game.isPlayingPossible()) {
		game.gameState = matchDraw;
		return;
	}
	switch (game.getCurrentPlayer())
	{
	case player1:
		game.gameState = playingPlayer1;
		gameOutput.showPlayer1Turn();
		break;
	case player2:
		game.gameState = playingPlayer2;
		gameOutput.showPlayer2Turn();
		break;
	default: break;
	}
}

void startAnimWaitingPlayers()
{
	#if BUTTONS_LED
		buttonsLed.doBlinkPlayers(true);
		buttonsLed.doChaseInputs(true);
	#endif
	gameOutput.lightFullWall(true);
}

void stopAnimWaitingPlayers()
{
	#if BUTTONS_LED
		buttonsLed.doBlinkPlayers(false);
		buttonsLed.doChaseInputs(false);
	#endif
	gameOutput.lightFullWall(false);
}


////////////////////////////////////////////////////////////////////////////////
// Program starting...
////////////////////////////////////////////////////////////////////////////////
#include "Solver.hpp"
GameSolver::Connect4::Solver solver;

void setup()
{
	randomSeed(analogRead(0));
#if DEBUG
	doInitHelper();
#endif
	doInitGame();
	gameOutputAudio.playPowerOn();
	gameOutput.showTouchSomething();



	GameSolver::Connect4::Position P;
	String thegame = "445354445524252";
	int res = P.play("445354445524252");
	if(res != thegame.length())
	{
		debug("Solve error:" + String(res) + "\n");
	} else {
		solver.reset();
		debug("GO!\n");
		unsigned long start = millis();
		int score = solver.solve(P, false);
		unsigned long stop = millis();
		debug("Time: " + String(stop-start) + "\n");
		debug("Score: " + String(score) + " Nodes: " + String((unsigned long)(solver.getNodeCount())) + "\n");
		if(score == 0)
		{
			debug("nobody can win\n");
		}
		if(score > 0)
		{
			debug("Win in " + String(22 - score) + " moves\n");
		}
		if(score < 0)
		{
			debug("Loose in " + String(-score) + " moves\n");
		}
	}
	Serial.send_now();
}

////////////////////////////////////////////////////////////////////////////////
// Endless loop
////////////////////////////////////////////////////////////////////////////////

void loop()
{
	// get the player's input
	// **********************
	gameInput.loop();
	gameInputAudio.loop();
	gameOutput.loop();
	gameOutputAudio.loop();

	// start the loop
	// *********************
	gameInput.startLoop();
	gameInputAudio.startLoop();
	gameOutput.startLoop();
	gameOutputAudio.startLoop();

	// actions are possible against gamestate
	// **************************************
	switch (game.gameState)
	{
		// not playing, just waiting for someone touching something...
		// ***********************************************************
	case waitingTouch:
		if (gameInput.hasInput())
		{
			game.gameState = choosingPlayersNumber;
			gameOutput.clearTiles();
			gameOutput.showChoosePlayersNumber();
			stopAnimWaitingPlayers();
			#if BUTTONS_LED
				buttonsLed.doBlinkPlayers(true);
			#endif
		}
		break;

		// waiting to know if here is 1 or 2 players
		// *****************************************
	case choosingPlayersNumber:
		if (gameInput.hasInput())
		{
			switch (gameInput.getAction())
			{
			case actionReset:
				gameOutputAudio.playGoodChoice();
				player1IsIA = true;
				player2IsIA = true;
				game.gameState = startingNewGame;
				gameOutput.showIaVsIa();
				#if BUTTONS_LED
					buttonsLed.doBlinkPlayers(false);
				#endif
				break;
			case actionPlayer1:
			case actionColumn1:
				gameOutputAudio.playGoodChoice();
				player1IsIA = false;
				player2IsIA = true;
				game.gameState = startingNewGame;
				gameOutput.showPlayerVsIa();
				#if BUTTONS_LED
					buttonsLed.doBlinkPlayers(false);
				#endif
				break;
			case actionPlayer2:
			case actionColumn2:
				gameOutputAudio.playGoodChoice();
				player1IsIA = false;
				player2IsIA = false;
				game.gameState = startingNewGame;
				gameOutput.showPlayerVsPlayer();
				#if BUTTONS_LED
					buttonsLed.doBlinkPlayers(false);
				#endif
				break;
			default: 
				gameOutputAudio.playBadChoice();
				break;
			}
		}
		break;

		// we are starting a new game session
		// **********************************
	case startingNewGame:
		game.startNewGame();
		gameOutput.drawBoard(game.getBoard());
		game.gameState = choosingWhoStart;
#if DEBUG
		debug(F("new game\n"));
		game.dumpGame();
#endif
		gameOutput.showDecideWhoStart();
		break;

		// determining which player is starting the game
		//**********************************************
	case choosingWhoStart:
		if(random(2) == 1)
		{
			#if DEBUG
				debug(F("Player 1 is starting\n"));
			#endif
			game.setCurrentPlayer(player1);
		} else {
			#if DEBUG
				debug(F("Player 2 is starting\n"));
			#endif
			game.setCurrentPlayer(player2);
		}
		gameTurn();
		gameOutputAudio.playStartGame();
		break;

		// Player 1 must choose where he put his token
		// ******************************************
	case playingPlayer1:
		game.gameState = choosingColumn;
		#if BUTTONS_LED
			buttonsLed.doBlinkOneLed(LED_PLAYER_1, true);
		#endif
		break;

		// Player 2 must choose where he put his token
		// ******************************************
	case playingPlayer2:
		game.gameState = choosingColumn;
		#if BUTTONS_LED
			buttonsLed.doBlinkOneLed(LED_PLAYER_2, true);
		#endif
		break;

		// Waiting for the current player to choose a column for his token
		// ***************************************************************
	case choosingColumn:
		if (game.getCurrentPlayer() == player1 && player1IsIA)
		{
			gameOutputAudio.playIAThinking();
			playColumn = game.getIndexPlayingForPlayerIA(player1);
#if DEBUG
			debug(F("(IA)"));
#endif
			game.gameState = puttingToken;
		}
		if (game.getCurrentPlayer() == player2 && player2IsIA)
		{
			gameOutputAudio.playIAThinking();
			playColumn = game.getIndexPlayingForPlayerIA(player2);
#if DEBUG
			debug(F("(IA)"));
#endif
			game.gameState = puttingToken;
		}
		if (gameInput.hasInput())
		{
			switch (gameInput.getAction())
			{
				case actionColumn1:
					playColumn = 0;
					game.gameState = puttingToken;
					break;
				case actionColumn2:
					playColumn = 1;
					game.gameState = puttingToken;
					break;
				case actionColumn3:
					playColumn = 2;
					game.gameState = puttingToken;
					break;
				case actionColumn4:
					playColumn = 3;
					game.gameState = puttingToken;
					break;
				case actionColumn5:
					playColumn = 4;
					game.gameState = puttingToken;
					break;
				case actionColumn6:
					playColumn = 5;
					game.gameState = puttingToken;
					break;
				case actionColumn7:
					playColumn = 6;
					game.gameState = puttingToken;
					break;
				default:
					gameOutputAudio.playBadChoice();
					break;
			}
		}
		break;

		// A player has choosen a column for his token
		// *******************************************
	case puttingToken:
		playLine = game.getRowPlayingColumn(playColumn);
		if (playLine == NO_VALUE)
		{
			gameOutputAudio.playBadChoice();
			game.gameState = badColumn;
#if DEBUG
			debug(String(playColumn).c_str());
			debug(F("=bad column\n"));
#endif
		}
		else
		{
			gameOutputAudio.playGoodChoice();
#if DEBUG
			debug(String(playColumn).c_str());
			debug(F("\n"));
#endif
			#if BUTTONS_LED
				buttonsLed.doBlinkOneLed(LED_PLAYER_1, false);
				buttonsLed.doBlinkOneLed(LED_PLAYER_2, false);
			#endif
			game.gameState = tokenAnimation;
			CaseLocation location;
			location.index = playColumn;
			location.row = playLine;
			gameOutput.setTiles(location, game.getCurrentPlayer());
		}
		game.calculateHints();
		switch(game.getHints())
		{
			case hintCanWin:
				if (game.getCurrentPlayer() == player2)
					gameOutputAudio.playWinningTeasing();
				else
					gameOutputAudio.playLoosingAlert();
				break;
			case hintCanLoose:
				if (game.getCurrentPlayer() == player2)
					gameOutputAudio.playLoosingAlert();
				else
					gameOutputAudio.playWinningTeasing();
				break;
			case hintSureToLoose:
				if (game.getCurrentPlayer() == player2)
					gameOutputAudio.playLoosingAlert();
				else
					gameOutputAudio.playWinningTeasing();
				break;
			default:
				break;
		}
#if DEBUG
		game.dumpGame();
#endif
		break;

		// It is not a valid column
		// ************************
	case badColumn:
		gameTurn();
		break;

		// It's a valid column, so play it!
		// ********************************
	case tokenAnimation:
		gameOutput.drawBoard(game.getBoard());
		winner = game.isSomeoneWinner();
		if (!winner)
		{
			if (game.isPlayingPossible())
			{
				gameOutput.showHints(game.getWinHints(), game.getLooseHints());
				game.nextPlayer();
				gameTurn();
			}
			else
			{
				game.gameState = matchDraw;
				gameOutput.showMatchDraw();
				#if BUTTONS_LED
					buttonsLed.doChaseInputs(true);
				#endif
			}
		}
		else
		{
			#if BUTTONS_LED
				buttonsLed.doBlinkInputs(true);
			#endif
			switch (game.getWhoWin())
			{
				case player1:
					gameOutputAudio.playWin();
					game.gameState = animationWinnerPlayer1;
					gameOutput.showWinPlayer1();
					break;
				case player2:
					gameOutputAudio.playLoose();
					game.gameState = animationWinnerPlayer2;
					gameOutput.showWinPlayer2();
					break;
				default:
				break;
			}
			gameOutput.showWinningCases(game.getWinningCases());
		}
		break;

		// Nobody win
		// **********
	case matchDraw:
		game.gameState = waitingTouch;
		break;

		// Player 1 has won!
		// *****************
	case animationWinnerPlayer1:
		game.gameState = waitingTouch;
#if DEBUG
		debug(F("anim1\n"));
#endif
		break;

		// Player 2 has won!
		// *****************
	case animationWinnerPlayer2:
		game.gameState = waitingTouch;
#if DEBUG
		debug(F("anim2\n"));
#endif
		break;

	} // switch (game.gameState)

	// end the loop
	// ************
	gameOutput.endLoop();
	gameOutputAudio.endLoop();
	gameInput.endLoop();
	gameInputAudio.endLoop();

	if (gameInputAudio.hasInput()) {
		switch (gameInputAudio.getAction())
		{
			case actionVolumeMuteOnOff:
#if DEBUG
				debug(F("Push MUTE ON/OFF\n"));
#endif			
				gameOutputAudio.muteOnOff();
				break;
			case actionVolumeUp:
				gameOutputAudio.volumeUp();
				break;
			case actionVolumeDown:
				gameOutputAudio.volumeDown();
				break;
			default: break;
		}
	}
}

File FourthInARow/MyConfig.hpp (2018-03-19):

#ifndef MYCONFIG_HPP
#define MYCONFIG_HPP

// Il s'agit du seul fichier à modifier.
// Vous définissez le matériel que vous avez
// et la configuration que vous avez construite.


////////////////////////////////////////////////////////////////////////////////
// Paramètres de fonctionnement du programme
////////////////////////////////////////////////////////////////////////////////

// mettre 1 pour être en mode debug, sinon mettre 0
// En mode debug, il y a énormément d'informations qui seront envoyées
// à votre PC/Mac/Linux sur la console série

#define DEBUG 1


////////////////////////////////////////////////////////////////////////////////
// Définir la carte électronique que vous utilisez
////////////////////////////////////////////////////////////////////////////////

// si vous utilisez le programme Arduino
// *************************************
// mettre 1 à votre carte électronique 
// et 0 pour les autres
// il ne doit y avoir qu'un seul 1 !

// si vous utilisez platformIO (avec Atom ou Visual Studio Code)
// *************************************************************
// mettre en commentaire car c'est géré automatiquement
// dans le fichier platformio.ini du projet

// 1 si carte ESP32, sinon mettre 0
// impossible à utiliser car ça manque de pinouilles !
//#define ESP32 0

// 1 si carte TEENSY35 / TEENSY36, sinon mettre 0
#define TEENSY3x 1

// 1 si carte ARDUINO MEGA 2560, sinon mettre 0
// impossible à utiliser avec l'IA
//#define MEGA2560 1

// 1 si carte ARDUINO UNO, sinon mettre 0
// impossible à compiler sur UNO : pas assez de mémoire !
//#define UNO 1

////////////////////////////////////////////////////////////////////////////////
// Paramètres définissant votre installation
////////////////////////////////////////////////////////////////////////////////

// mettre 1 si vous avez le matériel correspondant


// les actions des joueurs
// ***********************

// 1 - les actions de jeu
/////////////////////////

// si aucun dispositif d'actions installé
#define GAME_INPUT_DUMMY 0

// utilisation de la console Série du PC/Mac/Linux /!\ #define DEBUG doit être à 1
#define GAME_INPUT_SERIAL 1

// dispositif à base de 7 boutons (1 par colonne) + 2 boutons choix du nombre de joueurs
#define GAME_INPUT_9BUTTONS 0
#if !GAME_INPUT_9BUTTONS
	#define BUTTON_COLUMN_1 0
	#define BUTTON_COLUMN_2 0
	#define BUTTON_COLUMN_3 0
	#define BUTTON_COLUMN_4 0
	#define BUTTON_COLUMN_5 0
	#define BUTTON_COLUMN_6 0
	#define BUTTON_COLUMN_7 0
	#define BUTTON_COLUMN_PLAYER_1 0
	#define BUTTON_COLUMN_PLAYER_2 0
#else
	// les boutons d'arcade sont-ils lumineux ? (avec une led)
	#define BUTTONS_LED 0
	// n° de la led 
	#define LED_PLAYER_1 7
	#define LED_PLAYER_2 8
	#if ESP32
		// SDA/SCL/A6/A7/A8/A9/A10/A12/21
		#define BUTTON_COLUMN_1 23
		#define BUTTON_COLUMN_2 22
		#define BUTTON_COLUMN_3 14
		#define BUTTON_COLUMN_4 32
		#define BUTTON_COLUMN_5 15
		#define BUTTON_COLUMN_6 33
		#define BUTTON_COLUMN_7 27
		#define BUTTON_COLUMN_PLAYER_1 13
		#define BUTTON_COLUMN_PLAYER_2 21
		#if BUTTONS_LED
			// 
			#define BUTTON_LED_1 0
			#define BUTTON_LED_2 0
			#define BUTTON_LED_3 0
			#define BUTTON_LED_4 0
			#define BUTTON_LED_5 0
			#define BUTTON_LED_6 0
			#define BUTTON_LED_7 0
			#define BUTTON_LED_PLAYER_1 0
			#define BUTTON_LED_PLAYER_2 0
		#endif
	#endif
	#if TEENSY3x
		#define BUTTON_COLUMN_1 24
		#define BUTTON_COLUMN_2 25
		#define BUTTON_COLUMN_3 26
		#define BUTTON_COLUMN_4 27
		#define BUTTON_COLUMN_5 28
		#define BUTTON_COLUMN_6 29
		#define BUTTON_COLUMN_7 30
		#define BUTTON_COLUMN_PLAYER_1 31
		#define BUTTON_COLUMN_PLAYER_2 32
		#if BUTTONS_LED
			#define BUTTON_LED_1 0
			#define BUTTON_LED_2 1
			#define BUTTON_LED_3 2
			#define BUTTON_LED_4 3
			#define BUTTON_LED_5 4
			#define BUTTON_LED_6 5
			#define BUTTON_LED_7 6
			#define BUTTON_LED_PLAYER_1 7
			#define BUTTON_LED_PLAYER_2 8
		#endif
	#endif
	#if MEGA2560
		#define BUTTON_COLUMN_1 0
		#define BUTTON_COLUMN_2 0
		#define BUTTON_COLUMN_3 0
		#define BUTTON_COLUMN_4 0
		#define BUTTON_COLUMN_5 0
		#define BUTTON_COLUMN_6 0
		#define BUTTON_COLUMN_7 0
		#define BUTTON_COLUMN_PLAYER_1 0
		#define BUTTON_COLUMN_PLAYER_2 0
		#if BUTTONS_LED
			#define BUTTON_LED_1 0
			#define BUTTON_LED_2 0
			#define BUTTON_LED_3 0
			#define BUTTON_LED_4 0
			#define BUTTON_LED_5 0
			#define BUTTON_LED_6 0
			#define BUTTON_LED_7 0
			#define BUTTON_LED_PLAYER_1 0
			#define BUTTON_LED_PLAYER_2 0
		#endif
	#endif
	#if UNO
		#define BUTTON_COLUMN_1 0
		#define BUTTON_COLUMN_2 0
		#define BUTTON_COLUMN_3 0
		#define BUTTON_COLUMN_4 0
		#define BUTTON_COLUMN_5 0
		#define BUTTON_COLUMN_6 0
		#define BUTTON_COLUMN_7 0
		#define BUTTON_COLUMN_PLAYER_1 0
		#define BUTTON_COLUMN_PLAYER_2 0
		#if BUTTONS_LED
			#define BUTTON_LED_1 0
			#define BUTTON_LED_2 0
			#define BUTTON_LED_3 0
			#define BUTTON_LED_4 0
			#define BUTTON_LED_5 0
			#define BUTTON_LED_6 0
			#define BUTTON_LED_7 0
			#define BUTTON_LED_PLAYER_1 0
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

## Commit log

2017-12-18 retour à la ligne
2017-12-20 configure platformio for arduino mega
2017-12-21 implement 9 buttons input + debug
2017-12-22 gameinputaudio OK and rotary switch EC11 implement and test
2017-12-25 lot of debug + implement LED WS2801
2017-12-29 add 3D mobele openscad
    [bouton_arcade.scad, dessus.scad, jeu complet.scad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]
2017-12-29 3D : dimensions tôle supérieur
    [dessus.scad, jeu complet.scad, parametre.scad]
2017-12-29 3D: add dessous
    [dessous.scad, dessus.scad, jeu complet.scad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]
2017-12-29 3D : debug
    [dessous.scad, dessus.scad, grille_led.scad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]
2017-12-29 3D : assemblage + commentaires
    [bouton_arcade.scad, dessous.scad, dessus.scad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]
2017-12-29 3D : ajout du côté gauche
    [cote_gauche.scad, jeu complet.scad, parametre.scad]
2017-12-30 3D : add cote droit + HP
    [bouton_arcade.scad, cote_droit.scad, cote_gauche.scad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]
2017-12-30 3D : add EC11
    [bouton_arcade.scad, cote_droit.scad, cote_gauche.scad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]
2017-12-30 3D : tuning
    [haut_parleur_HP8R.scad, jeu complet.scad, parametre.scad]
2017-12-30 3D : add embase
    [cote_droit.scad, dessous.scad, embase.scad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]
2017-12-30 3D : add LED and tuning to cancel conflict
    [bouton_arcade.scad, cote_droit.scad, cote_gauche.scad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]
2017-12-31 3D: tuning rendu
    [jeu complet.scad]
2017-12-31 3D : ajout dessins
    [cote_droit.scad, cote_gauche.scad, logo_ia.scad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]
2018-01-01 3D add text and logo
    [cote_droit.scad, dessous.scad, logo_club_forme.scad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]
2018-01-08 3D: generate STL export
    3D: generate STL export
    [cote_droit.stl, cote_gauche.stl, dessous.stl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]
2018-01-18 Led WS2813
    [cote_droit.scad, embase.scad, parametre.scad]
2018-01-19 LED for second player
    [bouton_arcade.scad, cote_droit.scad, cote_droit.stl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]
2018-01-29 update VScode
    [bouton_arcade.scad, cote_droit.scad, cote_droit.stl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]
2018-02-14 add buttons lights + animation
    [bouton_arcade.scad, cote_droit.scad, cote_droit.stl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]
2018-02-16 conf teensy
2018-02-16 export DXF
    [cote_droit.dxf, cote_droit.scad, cote_gauche.dxf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]
2018-02-17 fine tuning
    [cote_droit.scad, cote_gauche.scad, dessous.scad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]
2018-02-20 add spacer
    [grille_led.scad, jeu complet.scad, parametre.scad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]
2018-02-23 tirage au Techshop
    [cote_droit.dxf, cote_gauche.dxf, dessous.dxf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]
2018-02-26 reglage led
2018-02-27 leds position
2018-03-14 generique def of TEENSY
2018-03-16 teensy 3.5
